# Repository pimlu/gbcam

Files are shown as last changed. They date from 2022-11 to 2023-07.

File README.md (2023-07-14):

## Gameboy Camera webcam

This project turns the "eyeball" of the Gameboy Camera into a webcam.

## PCB design

Made in KiCad, check out the boards directory.

## Building, flashing

Run `source setup.sh`, then `./flash.sh`. You can run `./serial.sh` in another tab to show the log output. `./flash.sh` will wait until it sees the device (you have to press down BOOTSEL + RESET).

## MacOS eject notifications
Adafruit has a [wonderful blog](https://blog.adafruit.com/2021/05/11/how-to-tone-down-macos-big-surs-circuitpy-eject-notifications/) showing you how to tone down the annoying "disk ejected unsafely" notifications. It doesn't remove it but at least they auto-dismiss.

## Important assembly note

In rev1, the footprint for the JST connector (the one hooked up to the gameboy camera) is backwards. It needs to be turned 180 - fortunately there is just barely enough clearance that the board still works if you flip it around.

## Pinout

See pinout.h

## Component docs

SHARP LS013B7DH05: [Programming Sharp’s Memory LCDs](https://www.sharpsde.com/fileadmin/products/Displays/2016_SDE_App_Note_for_Memory_LCD_programming_V1.3.pdf)

M64283FP (GB Camera): No official online datasheet (it's from the 90s) but there are sources available. [MITSUBISHI Image Sensor (Artificial Retina Chip)](https://github.com/Raphael-Boichot/Play-with-the-Game-Boy-Camera-Mitsubishi-M64282FP-sensor/blob/main/Additionnal%20informations/Mitsubishi%20Integrated%20Circuit%20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)

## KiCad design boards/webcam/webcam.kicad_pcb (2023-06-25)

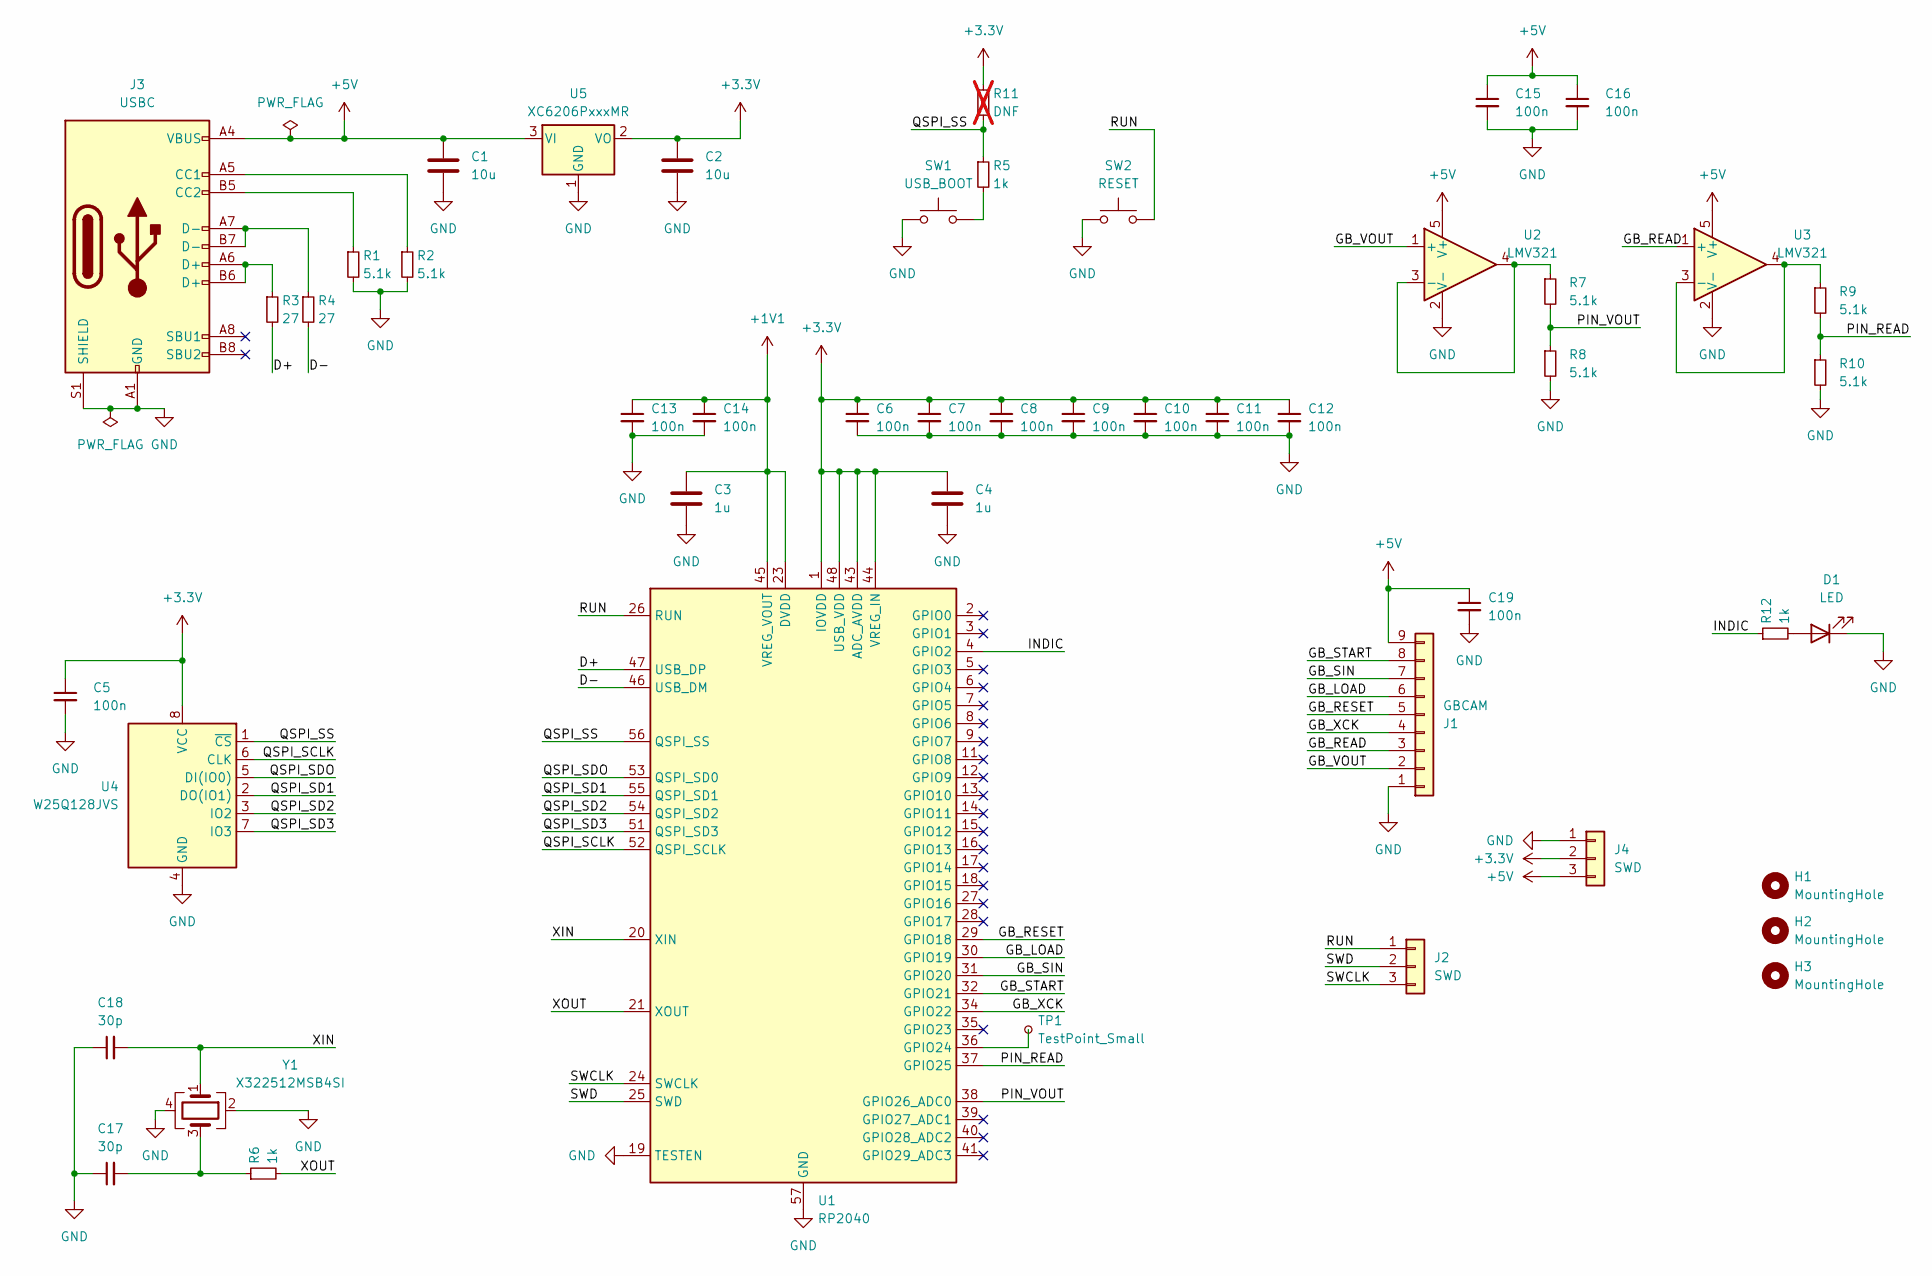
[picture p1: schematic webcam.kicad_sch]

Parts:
C1, C2: 10u; C_0603_1608Metric; LCSC C96446
C3, C4: 1u; C_0402_1005Metric; LCSC C52923
C5, C6, C7, C8, C9, C10, C11, C12, C13, C14, C15, C16, C19: 100n; C_0402_1005Metric; LCSC C1525
C17, C18: 30p; C_0402_1005Metric; LCSC C1570
D1: LED; LED_0805_2012Metric; LCSC C84256
H1, H2, H3: MountingHole; gbcam_mount
J1: GBCAM; JST_ZH-9
J2, J4: SWD; PinHeader_1x03_P1.00mm_Vertical
J3: USBC; JLCPCB_USB_C_Receptacle_HRO_TYPE-C-31-M-12; LCSC C165948
R1, R2, R7, R8, R9, R10: 5.1k; R_0402_1005Metric; LCSC C25905
R3, R4: 27; R_0603_1608Metric; LCSC C25190
R5, R6, R12: 1k; R_0402_1005Metric; LCSC C11702
R11: DNF; R_0402_1005Metric; not fitted
SW1: USB_BOOT; SW_Push_1P1T_XKB_TS-1187A; LCSC C318884
SW2: RESET; SW_Push_1P1T_XKB_TS-1187A; LCSC C318884
TP1: TestPoint_Small; TestPoint_THTPad_D1.0mm_Drill0.5mm
U1: RP2040; QFN-56-1EP_7x7mm_P0.4mm_EP3.2x3.2mm; LCSC C2040
U2, U3: LMV321; SOT-23-5; LCSC C7972
U4: W25Q128JVS; SOIC-8_5.23x5.23mm_P1.27mm; LCSC C97521
U5: XC6206PxxxMR; SOT-23-3; LCSC C5446
Y1: X322512MSB4SI; Crystal_SMD_3225-4Pin_3.2x2.5mm; LCSC C9002

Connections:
+1V1: C3.1, C13.1, C14.1, U1.23 (DVDD), U1.45 (VREG_VOUT), U1.50 (DVDD)
+3.3V: C2.1, C4.1, C5.1, C6.1, C7.1, C8.1, C9.1, C10.1, C11.1, C12.1, J4.2, R11.1, U1.1 (IOVDD), U1.10 (IOVDD), U1.22 (IOVDD), U1.33 (IOVDD), U1.42 (IOVDD), U1.43 (ADC_AVDD), U1.44 (VREG_IN), U1.48 (USB_VDD), U1.49 (IOVDD), U4.8 (VCC), U5.2 (VO)
+5V: C1.1, C15.1, C16.1, C19.1, J1.9, J3.A4 (VBUS), J3.A9 (VBUS), J3.B4 (VBUS), J3.B9 (VBUS), J4.3, U2.5 (V+), U3.5 (V+), U5.3 (VI)
/D+: R3.2, U1.47 (USB_DP)
/D-: R4.2, U1.46 (USB_DM)
/GB_LOAD: J1.6, U1.30 (GPIO19)
/GB_READ: J1.3, U3.1 (+)
/GB_RESET: J1.5, U1.29 (GPIO18)
/GB_SIN: J1.7, U1.31 (GPIO20)
/GB_START: J1.8, U1.32 (GPIO21)
/GB_VOUT: J1.2, U2.1 (+)
/GB_XCK: J1.4, U1.34 (GPIO22)
/INDIC: R12.1, U1.4 (GPIO2)
/PIN_READ: R9.2, R10.1, U1.37 (GPIO25)
/PIN_VOUT: R7.2, R8.1, U1.38 (GPIO26_ADC0)
/QSPI_SCLK: U1.52 (QSPI_SCLK), U4.6 (CLK)
/QSPI_SD1: U1.55 (QSPI_SD1), U4.2 (DO(IO1))
/QSPI_SD2: U1.54 (QSPI_SD2), U4.3 (IO2)
/QSPI_SD3: U1.51 (QSPI_SD3), U4.7 (IO3)
/QSPI_SDO: U1.53 (QSPI_SD0), U4.5 (DI(IO0))
/QSPI_SS: R5.1, R11.2, U1.56 (QSPI_SS), U4.1 (~CS)
/RUN: J2.1, SW2.2, U1.26 (RUN)
/SWCLK: J2.3, U1.24 (SWCLK)
/SWD: J2.2, U1.25 (SWD)
/XIN: C18.2, U1.20 (XIN), Y1.1
/XOUT: R6.2, U1.21 (XOUT)
GND: C1.2, C2.2, C3.2, C4.2, C5.2, C6.2, C7.2, C8.2, C9.2, C10.2, C11.2, C12.2, C13.2, C14.2, C15.2, C16.2, C17.1, C18.1, C19.2, D1.1 (K), J1.1, J3.A1 (GND), J3.A12 (GND), J3.B1 (GND), J3.B12 (GND), J3.S1 (SHIELD), J4.1, R1.2, R2.2, R8.2, R10.2, SW1.1, SW2.1, U1.19 (TESTEN), U1.57 (GND), U2.2 (V-), U3.2 (V-), U4.4 (GND), U5.1 (GND), Y1.2, Y1.4
unnamed: C17.2, R6.1, Y1.3
unnamed: D1.2 (A), R12.2
unnamed: J3.A5 (CC1), R2.1
unnamed: J3.B5 (CC2), R1.1
unnamed: J3.A6 (D+), J3.B6 (D+), R3.1
unnamed: J3.A7 (D-), J3.B7 (D-), R4.1
unnamed: R5.2, SW1.2
unnamed: TP1.1, U1.36 (GPIO24)
unnamed: R7.1, U2.3 (-), U2.4
unnamed: R9.1, U3.3 (-), U3.4

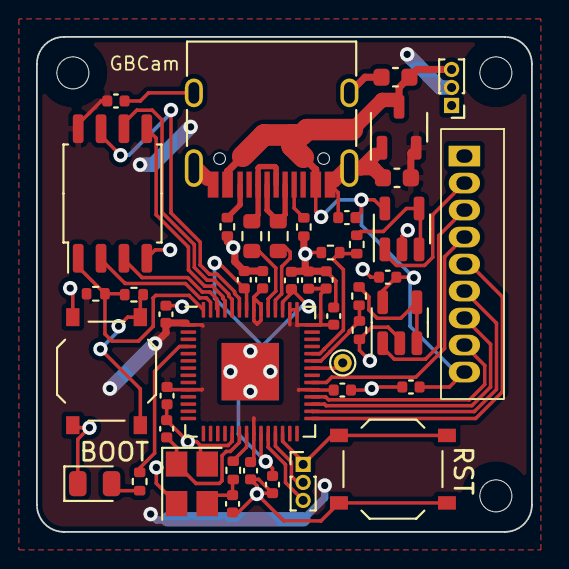
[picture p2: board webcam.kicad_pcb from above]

Board: 2 copper layers, 27.5 x 27.5 mm, 48 parts (0 on the bottom side), 37 nets.

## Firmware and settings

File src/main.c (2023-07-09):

/**
 * Copyright (c) 2020 Raspberry Pi (Trading) Ltd.
 *
 * SPDX-License-Identifier: BSD-3-Clause
 */

#include <stdio.h>
#include "pico/stdlib.h"
#include "pico/binary_info.h"
#include "hardware/spi.h"
#include "hardware/adc.h"
#include "pico/multicore.h"

#include "bsp/board.h"
#include "tusb.h"

#include "drivers/gbcam.h"
#include "drivers/usb/usb_serial.h"

#include "tasks/debug_led.h"
#include "tasks/video.h"

#include "core1.h"
#include "utils.h"


int main() {
    board_init();
    tusb_init();
    stdio_usb_init();
    tud_task();
    
    adc_init();
    gpio_init(BOARD_LED);
    gpio_set_dir(BOARD_LED, GPIO_OUT);

    // wait for USB to come up
    while(!tud_ready()) {
        tud_task();
    }
    wait_for_serial_hack();

    multicore_launch_core1(core1_main);
    
    printf("core0 init\n");

    // can't let main return otherwise it breaks core1
    while (true) {
        led_blinking_task();
        video_task();

        tud_task(); // tinyusb device task
    }

    return 0;
}

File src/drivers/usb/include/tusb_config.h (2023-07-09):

// based off the MIT licensed tinyUSB examples

#ifndef _TUSB_CONFIG_H_
#define _TUSB_CONFIG_H_

#ifdef __cplusplus
 extern "C" {
#endif

//--------------------------------------------------------------------
// COMMON CONFIGURATION
//--------------------------------------------------------------------

// defined by board.mk
#ifndef CFG_TUSB_MCU
  #error CFG_TUSB_MCU must be defined
#endif

// RHPort number used for device can be defined by board.mk, default to port 0
#ifndef BOARD_DEVICE_RHPORT_NUM
  #define BOARD_DEVICE_RHPORT_NUM     0
#endif

// RHPort max operational speed can defined by board.mk
// Default to Highspeed for MCU with internal HighSpeed PHY (can be port specific), otherwise FullSpeed
#ifndef BOARD_DEVICE_RHPORT_SPEED
  #if (CFG_TUSB_MCU == OPT_MCU_LPC18XX || CFG_TUSB_MCU == OPT_MCU_LPC43XX || CFG_TUSB_MCU == OPT_MCU_MIMXRT10XX || \
       CFG_TUSB_MCU == OPT_MCU_NUC505  || CFG_TUSB_MCU == OPT_MCU_CXD56 || CFG_TUSB_MCU == OPT_MCU_SAMX7X)
    #define BOARD_DEVICE_RHPORT_SPEED   OPT_MODE_HIGH_SPEED
  #else
    #define BOARD_DEVICE_RHPORT_SPEED   OPT_MODE_FULL_SPEED
  #endif
#endif

// Device mode with rhport and speed defined by board.mk
#if   BOARD_DEVICE_RHPORT_NUM == 0
  #define CFG_TUSB_RHPORT0_MODE     (OPT_MODE_DEVICE | BOARD_DEVICE_RHPORT_SPEED)
#elif BOARD_DEVICE_RHPORT_NUM == 1
  #define CFG_TUSB_RHPORT1_MODE     (OPT_MODE_DEVICE | BOARD_DEVICE_RHPORT_SPEED)
#else
  #error "Incorrect RHPort configuration"
#endif

#ifndef CFG_TUSB_OS
#define CFG_TUSB_OS               OPT_OS_NONE
#endif

// CFG_TUSB_DEBUG is defined by compiler in DEBUG build
// #define CFG_TUSB_DEBUG           0

/* USB DMA on some MCUs can only access a specific SRAM region with restriction on alignment.
 * Tinyusb use follows macros to declare transferring memory so that they can be put
 * into those specific section.
 * e.g
 * - CFG_TUSB_MEM SECTION : __attribute__ (( section(".usb_ram") ))
 * - CFG_TUSB_MEM_ALIGN   : __attribute__ ((aligned(4)))
 */
#ifndef CFG_TUSB_MEM_SECTION
#define CFG_TUSB_MEM_SECTION
#endif

#ifndef CFG_TUSB_MEM_ALIGN
#define CFG_TUSB_MEM_ALIGN          __attribute__ ((aligned(4)))
#endif

//--------------------------------------------------------------------
// DEVICE CONFIGURATION
//--------------------------------------------------------------------

#ifndef CFG_TUD_ENDPOINT0_SIZE
#define CFG_TUD_ENDPOINT0_SIZE    64
#endif

//------------- CLASS -------------//
#define CFG_TUD_HID               0
#define CFG_TUD_CDC               1
#define CFG_TUD_MSC               0
#define CFG_TUD_MIDI              0
#define CFG_TUD_VENDOR            0
#define CFG_TUD_VIDEO             1


#define CFG_TUD_CDC_RX_BUFSIZE    (TUD_OPT_HIGH_SPEED ? 512 : 64)
#define CFG_TUD_CDC_TX_BUFSIZE    (TUD_OPT_HIGH_SPEED ? 512 : 64)

// The number of video streaming interfaces
#define CFG_TUD_VIDEO_STREAMING  1

// video streaming endpoint size
#define CFG_TUD_VIDEO_STREAMING_EP_BUFSIZE  256

// use bulk endpoint for streaming interface
#define CFG_TUD_VIDEO_STREAMING_BULK 0


#ifdef __cplusplus
 }
#endif

#endif /* _TUSB_CONFIG_H_ */

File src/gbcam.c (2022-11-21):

/**
 * Copyright (c) 2020 Raspberry Pi (Trading) Ltd.
 *
 * SPDX-License-Identifier: BSD-3-Clause
 */

#include <stdio.h>
#include "pico/stdlib.h"
#include "pico/binary_info.h"
#include "hardware/spi.h"

#include "sharp.h"

#define LED 13


void dump(uint8_t* buf, size_t len) {
    for (size_t i=0; i<len; i++) {
        printf("%02x ", buf[i]);
    }
    printf("\n");
}

int main() {
    stdio_init_all();
    gpio_init(LED);
    gpio_set_dir(LED, GPIO_OUT);

    spi_sharp_init();

    bool vcom = false;
    while (true) {

        draw(vcom);

        sleep_ms(750);
        gpio_put(LED, 1);
        sleep_ms(250);
        gpio_put(LED, 0);

        vcom = !vcom;
    }


    return 0;
}

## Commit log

2023-06-13 more camera stuff, rearrange to new folder structure
2023-06-14 cam: add initialization logic for the gbcam
    Might have to sleep since the mcu is too fast
    [gbcam.c]
2023-06-15 gbcam: get sampling/clocks going
    Haven't tested it on the real camera but it's close.
    The RP2040 is really amazing
2023-06-24 kicad: create the gbcam pcb
    [webcam.kicad_pcb, webcam.kicad_sch]
2023-06-25 pcb: prepare for jlcpcb
    [webcam.kicad_pcb, webcam.kicad_sch]
2023-06-25 pcb: final prep for jlcpcb
    [webcam.kicad_pcb, webcam.kicad_sch]
2023-07-14 gbcam: make it work on the pcb
    yay!
